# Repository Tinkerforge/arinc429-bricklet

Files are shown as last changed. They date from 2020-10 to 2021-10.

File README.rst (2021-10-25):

ARINC429 Bricklet
=================

**This Bricklet is currently in development.**

This repository contains the firmware source code and the hardware design
files. The documentation generator configs can be found at
https://github.com/Tinkerforge/generators

Repository Content
------------------

software/:
 * examples/: Examples for all supported languages
 * build/: Compiled files
 * src/: Source code of firmware
 * Makefile: Makefile to build project

hardware/:
 * Contains KiCad project files and additionally schematics as PDF

datasheets/:
 * Contains datasheets for sensors and complex ICs that are used

Hardware
--------

The hardware is designed with the open source EDA Suite KiCad
(http://www.kicad.org). Before you are able to open the files,
you have to install the Tinkerforge kicad-libraries
(https://github.com/Tinkerforge/kicad-libraries). You can either clone
them directly in hardware/ or clone them in a separate folder and
symlink them into hardware/
(ln -s kicad_path/kicad-libraries project_path/hardware). After that you
can open the .pro file in hardware/ with KiCad and from there view and
modify the schematics and the PCB layout.

Software
--------

If you want to do your own Brick/Bricklet firmware development we highly
recommend that you use our build environment setup script and read the
tutorial (https://www.tinkerforge.com/en/doc/Tutorials/Tutorial_Build_Environment/Tutorial.html).

To compile the C code we recommend you to install the newest GNU Arm Embedded
Toolchain (https://launchpad.net/gcc-arm-embedded/+download).
You also need to install bricklib2 (https://github.com/Tinkerforge/bricklib2).

You can either clone it directly in software/src/ or clone it in a
separate folder and symlink it into software/src/
(ln -s bricklib_path/bricklib2 project_path/software/src/). Finally make sure to
have CMake installed (http://www.cmake.org/cmake/resources/software.html).

After that you can build the firmware by invoking make in software/.
The firmware (.zbin) can then be found in software/build/ and uploaded
with brickv (click button "Flashing" on start screen).

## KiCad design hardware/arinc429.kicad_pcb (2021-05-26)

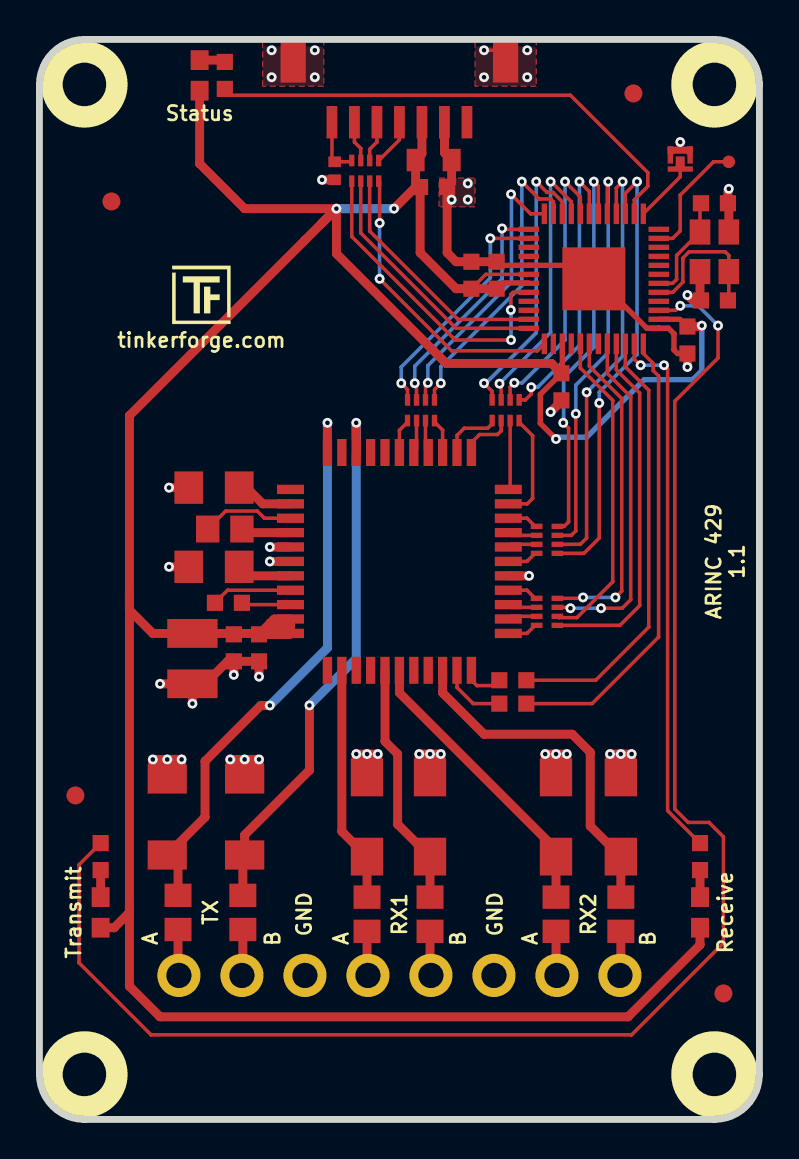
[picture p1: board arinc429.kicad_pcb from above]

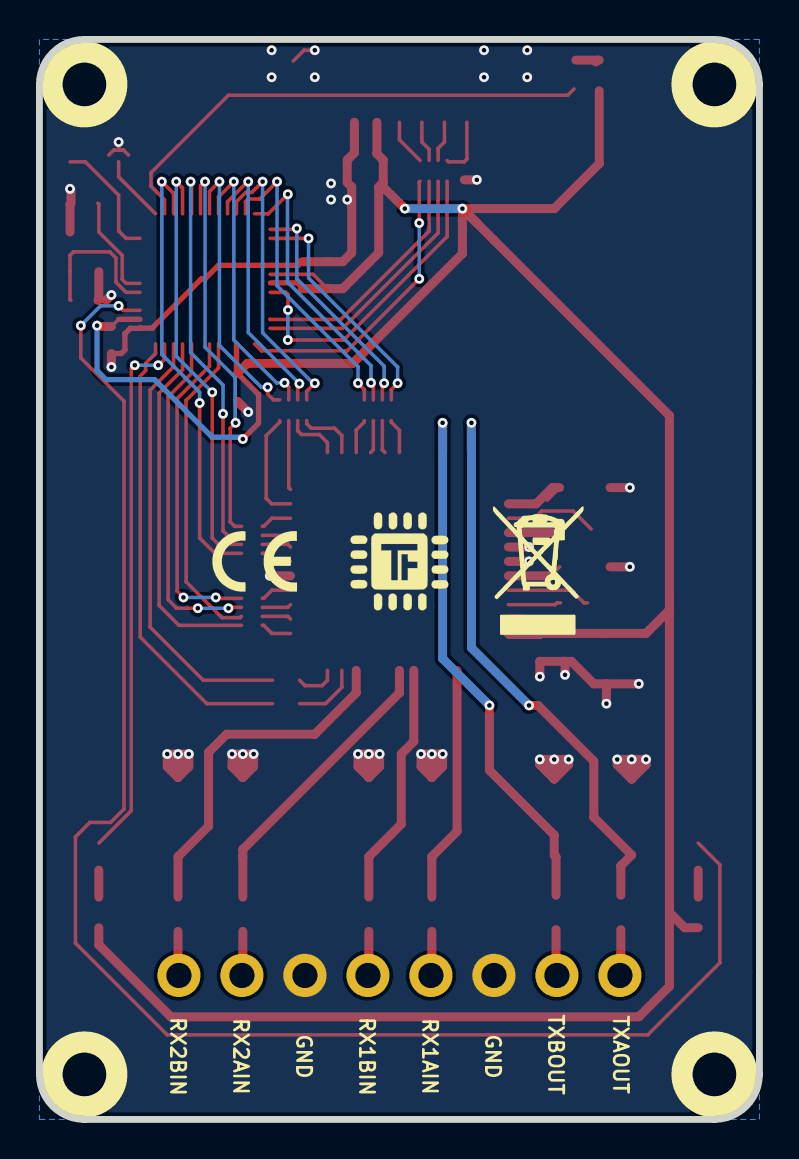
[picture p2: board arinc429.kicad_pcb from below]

Board: 2 copper layers, 40.0 x 60.0 mm, 58 parts (2 on the bottom side), 74 nets.

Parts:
C1: 10uF; C0805
C2: 1uF; C0603F
C3, C4, C5, C12: 100nF; C0603F
C6: 220nF; C0603F
C7: 220pF; C0402F
C8, C9: 10pF; C0603F
C10: 47uF; 3528-21
C11: 10nF; C0603F
C13, C15: 47uF/10V; C1206E
C14: 2,2uF/16V; 0805E
C16: 470nF/16V; 0603F
D1, D2: SMBJ-6.5CA; SMB
D3, D8, D9: blue; D0603E
D4, D5, D6, D7: SMAJ-6.5CA; DO-214AC
Fiducial_Mark: VAL**; Fiducial_Mark
Fiducial_Mark#2, Fiducial_Mark#3, Fiducial_Mark#4: VAL**; Fiducial_Mark
P1: CON-SENSOR2
P2: BOOT; SolderJumper
P3: DEBUG; DEBUG_PAD
P4: IND 8Pol; OQ_8P
R1, R10, R11: 1k; R0603F
R2, R3: 100; R0603F
R4, R5, R6, R7: 40,2k; R0805E
R8, R9: 31,6; R0805E
RP1: 82; 4X0402
RP2, RP3, RP4, RP5: 100; 4X0402
U1: XMC1404; QFN48-EP2
U2, U3, U4, U5: DRILL; DRILL_NP
U6: HI-3593PQIF; PQFP-44_10x10mm
VAL: WEEE_7mm
VAL#2: CE_5mm
X1: 16MHz; CRYSTAL_3225

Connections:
CLOCK: R3.2, U1.34
GND: C1.1, C2.1, C3.2, C4.2, C5.2, C6.2, C7.2, C8.2, C9.2, C10.2, C11.1, C12.1, C13.2, C15.2, D1.2, D2.2, D4.2, D5.2, D6.2, D7.2, P1.2, P1.EP, P2.1, P4.3, P4.6, U1.17, U1.37, U1.EP, U6.16, U6.38, U6.39, X1.3
M-CLK: RP5.3, U1.32
M-CS: RP5.1, U1.33
M-MISO: RP5.4, U1.30
M-MOSI: RP5.2, U1.29
MB1-1: RP2.1, U1.3
MB1-2: RP2.2, U1.4
MB1-3: RP2.3, U1.5
MB2-1: RP2.4, U1.6
MB2-2: RP3.1, U1.7
MB2-3: RP3.2, U1.8
unnamed: C7.1, P1.7, RP1.4
unnamed: C8.1, U1.41, X1.2
unnamed: C9.1, U1.42, X1.1
unnamed: C13.1, U6.35
unnamed: C14.1, U6.36
unnamed: C14.2, U6.37
unnamed: C15.1, U6.40
unnamed: C16.1, U6.41
unnamed: C16.2, U6.42
unnamed: D1.1, R9.2, U6.33
unnamed: D2.1, R8.2, U6.31
unnamed: D3.2, R11.2
unnamed: D4.1, R7.2, U6.2
unnamed: D5.1, R6.2, U6.5
unnamed: D6.1, R5.2, U6.6
unnamed: D7.1, R4.2, U6.9
unnamed: D8.2, R1.2
unnamed: D9.2, R10.2
unnamed: P1.4, RP1.1
unnamed: P1.5, RP1.2
unnamed: P1.6, RP1.3
unnamed: P2.2, U1.1
unnamed: P3.1, U1.47
unnamed: P4.1, R9.1
unnamed: P4.2, R8.1
unnamed: P4.4, R7.1
unnamed: P4.5, R6.1
unnamed: P4.7, R5.1
unnamed: P4.8, R4.1
unnamed: R2.1, U6.10
unnamed: R3.1, U6.11
unnamed: RP2.5, U6.20
unnamed: RP2.6, U6.19
unnamed: RP2.7, U6.18
unnamed: RP2.8, U6.17
unnamed: RP3.5, U6.24
unnamed: RP3.6, U6.23
unnamed: RP3.7, U6.22
unnamed: RP3.8, U6.21
unnamed: RP4.5, U6.28
unnamed: RP4.6, U6.27
unnamed: RP4.7, U6.26
unnamed: RP4.8, U6.25
unnamed: RP5.5, U6.15
unnamed: RP5.6, U6.14
unnamed: RP5.7, U6.13
unnamed: RP5.8, U6.12
R1FLAG: RP4.2, U1.12
R1INT: RP4.1, U1.11
R2FLAG: RP3.4, U1.10
R2INT: RP3.3, U1.9
RESET: R2.2, U1.36
RX_LED: R10.1, U1.39
S-CLK: RP1.7, U1.23
S-CS: RP1.8, U1.25
S-MISO: RP1.5, U1.20
S-MOSI: RP1.6, U1.24
Status_LED: R11.1, U1.2
TEMPY: RP4.3, U1.13
TFULL: RP4.4, U1.14
TX_LED: R1.1, U1.35
VCC: C1.2, C2.2, C3.1, C4.1, C5.1, C6.1, C10.1, C11.2, C12.2, D3.1, D8.1, D9.1, P1.3, U1.18, U1.19, U1.27, U1.38, U6.43, U6.44

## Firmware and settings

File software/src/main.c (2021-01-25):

/* arinc429-bricklet
 * Copyright (C) 2020 Olaf Lüke <olaf@tinkerforge.com>
 *
 * main.c: Initialization for ARINC429 Bricklet
 *
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
 * You should have received a copy of the GNU Lesser General Public
 * License along with this library; if not, write to the
 * Free Software Foundation, Inc., 59 Temple Place - Suite 330,
 * Boston, MA 02111-1307, USA.
 */

#include <stdio.h>
#include <stdbool.h>

#include "configs/config.h"

#include "bricklib2/bootloader/bootloader.h"
#include "bricklib2/hal/system_timer/system_timer.h"
#include "bricklib2/logging/logging.h"
#include "bricklib2/os/coop_task.h"

#include "arinc429.h"
#include "hi3593.h"
#include "communication.h"

extern CoopTask arinc429_task;


/****************************************************************************/
/* MAIN()                                                                   */
/****************************************************************************/

int main(void)
{
//	// start logging service
//	logging_init();
//	logd("Start ARINC429 Bricklet\n\r");

	// initialize communication
	communication_init();

	// initialize A429 task
	coop_task_init(&arinc429_task, arinc429_tick_task);

	// set initial system requests
	arinc429.system.change_request = 0xFF;  // request all updates

	// main-loop
	while(true)
	{
		// do housekeeping
		bootloader_tick();

		// do communication
		communication_tick();

		// do A429 specific operations
		arinc429_tick();
	}
}

//~~~~~~~~~~~~~~~~~~~~~~~~~~~~~~~~~~~~~~~~~~~~~~~~~~~~~~~~~~~~~~~~~~~~~~~~~~~~

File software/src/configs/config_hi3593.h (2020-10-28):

/* arinc429-bricklet
 * Copyright (C) 2020 Olaf Lüke <olaf@tinkerforge.com>
 *
 * config_hi3593.h: Configuration for HI-3593 ARINC429 IC
 *
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
 * You should have received a copy of the GNU Lesser General Public
 * License along with this library; if not, write to the
 * Free Software Foundation, Inc., 59 Temple Place - Suite 330,
 * Boston, MA 02111-1307, USA.
 */

#ifndef CONFIG_HI3593_H
#define CONFIG_HI3593_H

#include "xmc_gpio.h"
#include "xmc_spi.h"

#define HI3593_SPI_BAUDRATE           1000000
#define HI3593_USIC_CHANNEL           USIC1_CH1
#define HI3593_USIC_SPI               XMC_SPI1_CH1

#define HI3593_RX_FIFO_SIZE           XMC_USIC_CH_FIFO_SIZE_32WORDS
#define HI3593_RX_FIFO_POINTER        0
#define HI3593_TX_FIFO_SIZE           XMC_USIC_CH_FIFO_SIZE_32WORDS
#define HI3593_TX_FIFO_POINTER        32

#define HI3593_CLOCK_PASSIVE_LEVEL    XMC_SPI_CH_BRG_SHIFT_CLOCK_PASSIVE_LEVEL_0_DELAY_ENABLED
#define HI3593_CLOCK_OUTPUT           XMC_SPI_CH_BRG_SHIFT_CLOCK_OUTPUT_SCLK
#define HI3593_SLAVE                  XMC_SPI_CH_SLAVE_SELECT_0

#define HI3593_SCLK_PORT              XMC_GPIO_PORT0
#define HI3593_SCLK_PIN               3
#define HI3593_SCLK_PIN_MODE          (XMC_GPIO_MODE_OUTPUT_PUSH_PULL_ALT8 | P0_3_AF_U1C1_SCLKOUT)

#define HI3593_SELECT_PORT            XMC_GPIO_PORT0
#define HI3593_SELECT_PIN             4
#define HI3593_SELECT_PIN_MODE        (XMC_GPIO_MODE_OUTPUT_PUSH_PULL_ALT8 | P0_4_AF_U1C1_SELO0)

#define HI3593_MOSI_PORT              XMC_GPIO_PORT0
#define HI3593_MOSI_PIN               0
#define HI3593_MOSI_PIN_MODE          (XMC_GPIO_MODE_OUTPUT_PUSH_PULL_ALT9 | P0_0_AF_U1C1_DOUT0)

#define HI3593_MISO_PORT              XMC_GPIO_PORT0
#define HI3593_MISO_PIN               1
#define HI3593_MISO_INPUT             XMC_USIC_CH_INPUT_DX0
#define HI3593_MISO_SOURCE            0b001 // DX0B


#define HI3593_RX_LED                 P0_6
#define HI3593_RX_LED_PORT            XMC_GPIO_PORT0
#define HI3593_RX_LED_PIN             6
#define HI3593_TX_LED                 P0_8
#define HI3593_TX_LED_PORT            XMC_GPIO_PORT0
#define HI3593_TX_LED_PIN             8

#define HI3593_CLOCK                  P0_5
#define HI3593_CLOCK_SLICE_NUMBER     0
#define HI3593_CLOCK_PERIOD           96 // 96MHz / 96 = 1MHz
#define HI3593_CLOCK_PORT             XMC_GPIO_PORT0
#define HI3593_CLOCK_PIN              5
#define HI3593_RESET                  P0_7
#define HI3593_RESET_PORT             XMC_GPIO_PORT0
#define HI3593_RESET_PIN              7

#define HI3593_INPUT_PINS_NUM         12

#define HI3593_MB11_PORT              XMC_GPIO_PORT2
#define HI3593_MB11_PIN               0
#define HI3593_MB11_INDEX             0
#define HI3593_MB12_PORT              XMC_GPIO_PORT2
#define HI3593_MB12_PIN               1
#define HI3593_MB12_INDEX             1
#define HI3593_MB13_PORT              XMC_GPIO_PORT2
#define HI3593_MB13_PIN               2
#define HI3593_MB13_INDEX             2
#define HI3593_MB21_PORT              XMC_GPIO_PORT2
#define HI3593_MB21_PIN               3
#define HI3593_MB21_INDEX             3
#define HI3593_MB22_PORT              XMC_GPIO_PORT2
#define HI3593_MB22_PIN               4
#define HI3593_MB22_INDEX             4
#define HI3593_MB23_PORT              XMC_GPIO_PORT2
#define HI3593_MB23_PIN               5
#define HI3593_MB23_INDEX             5

#define HI3593_R2INT_PORT             XMC_GPIO_PORT2
#define HI3593_R2INT_PIN              6
#define HI3593_R2INT_INDEX            6
#define HI3593_R2FLAG_PORT            XMC_GPIO_PORT2
#define HI3593_R2FLAG_PIN             7
#define HI3593_R2FLAG_INDEX           7
#define HI3593_R1INT_PORT             XMC_GPIO_PORT2
#define HI3593_R1INT_PIN              8
#define HI3593_R1INT_INDEX            8
#define HI3593_R1FLAG_PORT            XMC_GPIO_PORT2
#define HI3593_R1FLAG_PIN             9
#define HI3593_R1FLAG_INDEX           9

#define HI3593_TEMPTY_PORT            XMC_GPIO_PORT2
#define HI3593_TEMPTY_PIN             10
#define HI3593_TEMPTY_INDEX           10
#define HI3593_TFULL_PORT             XMC_GPIO_PORT2
#define HI3593_TFULL_PIN              11
#define HI3593_TFULL_INDEX            11

#endif

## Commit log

2020-06-26 first schematic
    [arinc429.sch]
2020-06-26 first pcb
    [arinc429.kicad_pcb, arinc429.sch]
2020-06-29 pcb design
    [arinc429.kicad_pcb]
2020-06-29 pcb prototyp
    [arinc429.kicad_pcb, arinc429.sch]
2020-06-29 ready for prototype
    [arinc429.kicad_pcb]
2020-06-29 fixed copper floodfill
    [arinc429.kicad_pcb]
2020-06-30 add description text on top side
    [arinc429.kicad_pcb, arinc429.sch]
2020-06-30 remove double text
    [arinc429.kicad_pcb]
2020-07-23 Add initial firmware stub implementation
    [cmake_config_custom.txt]
2020-07-23 changed spi pinout
    [arinc429.kicad_pcb, arinc429.sch]
2020-07-23 Add HI3593 pin and hardware unit defines
2020-07-23 Initialize pins and spi, add register read/write test
2020-07-24 Active spi fifo coop mutex
    This is necessary since we now can use SPI from the hi3593 tick
    as well as from a getter/setter
2020-07-24 Use 32 words per spi fifo
2020-07-24 Implement simple debug API
    Note: We du the SPI read/write directly in the communication
    setter/getter call here and the setter/getter is blocked as long
    as the communication takes.
    This makes sense for the debug code, but later on the firmware will
    have to do the more high-level logic in the hi3593 tick.
2020-07-24 Add simple RX/TX led logic
    For now we blink rx when we read registers and tx when we write registers
2020-08-26 Add data structure for ARINC429 state machine
    This is currently just for memory/stack size testing. We can
    still optimize it so the packing is not necessary and access
    of the data is faster.
2020-10-28 Fix LEDs
2021-01-25 Improve naming and small fixes
    [arinc429.c, arinc429.h, communication.h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]
2021-02-24 edited F.Paste layer
    [arinc429.kicad_pcb]
2021-05-26 added specific partnumber HI-3593PQIF
    [arinc429.kicad_pcb, arinc429.sch]
2021-10-25 Update KiCad link
    https://www.kicad.org/blog/2021/10/Avoid-links-to-former-kicad-domain/

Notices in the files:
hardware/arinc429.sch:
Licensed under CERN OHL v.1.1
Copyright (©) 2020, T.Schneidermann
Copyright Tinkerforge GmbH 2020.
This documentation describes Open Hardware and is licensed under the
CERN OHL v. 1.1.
